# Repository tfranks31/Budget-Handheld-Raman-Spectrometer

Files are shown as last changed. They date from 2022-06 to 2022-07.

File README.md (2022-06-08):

# Budget-Handheld-Raman-Spectrometer
An inexpensive DIY handheld Raman spectrometer! Ever want to make a handheld Raman spectrometer for under $300?
Probably not! However, matter is just about everywhere and makes up most of everything. It would be cool to have a 
device that tells you what something is made out of, and would be even cooler to build it yourself!

This repository serves as the main repository for this project, and contains source code, electrical schematics, CAD 
models, future plans, and documentation for it all.

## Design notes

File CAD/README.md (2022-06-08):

# CAD Models
Here exist all CAD models used for the handheld Raman spectrometer project.

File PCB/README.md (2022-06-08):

# PCB design and electrical schematics
Here exists all PCB designs and electrical schematics for the handheld Raman spectrometer project.

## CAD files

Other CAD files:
CAD/Collimating Ring.f3d
CAD/Longpass Ring.f3d
CAD/Test Stand.f3d

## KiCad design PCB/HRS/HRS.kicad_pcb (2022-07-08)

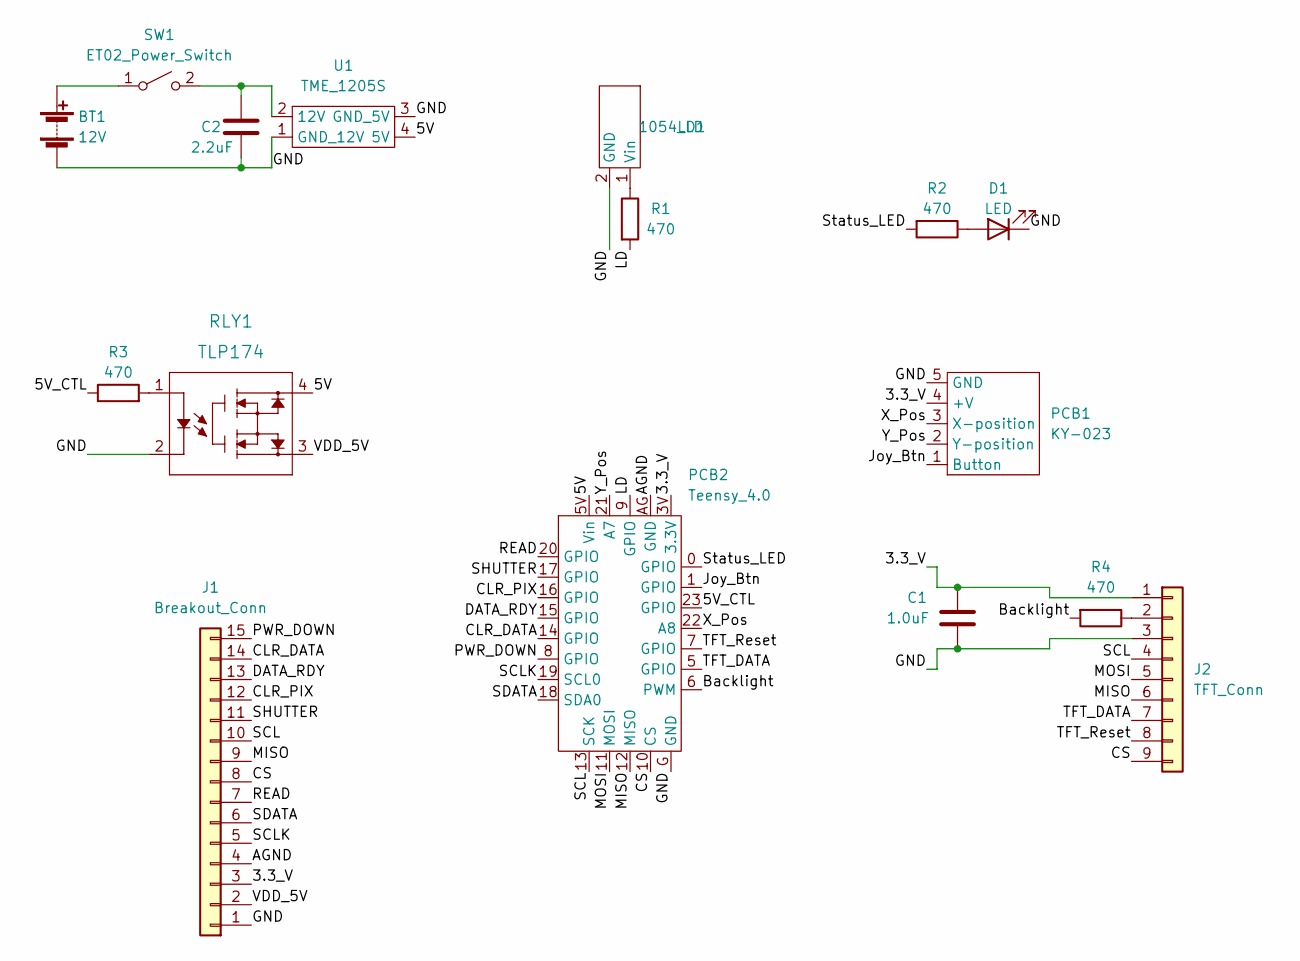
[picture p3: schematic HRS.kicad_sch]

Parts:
BT1: 12V; BAT&LD
C1: 1.0uF; C_0603_1608Metric
C2: 2.2uF; C_0603_1608Metric
D1: LED; LED_D5.0mm
J1: Breakout_Conn; Breakout-Connector-Female
J2: TFT_Conn
LD1: 1054_LD; BAT&LD
PCB1: KY-023; Ky-023
PCB2: Teensy_4.0; Teensy Headers
R1, R2, R3, R4: 470; R_0603_1608Metric
RLY1: TLP174
SW1: ET02_Power_Switch; ET02
U1: TME_1205S; TME 1205S

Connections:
/3.3_V: C1.2, J1.3, J2.1, PCB1.4 (+V), PCB2.3V (3.3V)
/5V: PCB2.5V (Vin), RLY1.4, U1.4 (5V)
/5V_CTL: PCB2.23 (GPIO), R3.1
/AGND: J1.4, PCB2.AG (GND)
/Backlight: PCB2.6 (PWM), R4.2
/CLR_DATA: J1.14, PCB2.14 (GPIO)
/CLR_PIX: J1.12, PCB2.16 (GPIO)
/CS: J1.8, J2.9, PCB2.10 (CS)
/DATA_RDY: J1.13, PCB2.15 (GPIO)
/GND: BT1.2 (-), C1.1, C2.1, D1.1 (K), J1.1, J2.3, LD1.2 (GND), PCB1.5 (GND), PCB2.G (GND), RLY1.2, U1.1 (GND_12V), U1.3 (GND_5V)
/Joy_Btn: PCB1.1 (Button), PCB2.1 (GPIO)
/LD: PCB2.9 (GPIO), R1.2
/MISO: J1.9, J2.6, PCB2.12 (MISO)
/MOSI: J2.5, PCB2.11 (MOSI)
/PWR_DOWN: J1.15, PCB2.8 (GPIO)
/READ: J1.7, PCB2.20 (GPIO)
/SCL: J1.10, J2.4, PCB2.13 (SCK)
/SCLK: J1.5, PCB2.19 (SCL0)
/SDATA: J1.6, PCB2.18 (SDA0)
/SHUTTER: J1.11, PCB2.17 (GPIO)
/Status_LED: PCB2.0 (GPIO), R2.2
/TFT_DATA: J2.7, PCB2.5 (GPIO)
/TFT_Reset: J2.8, PCB2.7 (GPIO)
/VDD_5V: J1.2, RLY1.3
/X_Pos: PCB1.3 (X-position), PCB2.22 (A8)
/Y_Pos: PCB1.2 (Y-position), PCB2.21 (A7)
unnamed: BT1.1 (+), SW1.1 (A)
unnamed: C2.2, SW1.2 (B), U1.2 (12V)
unnamed: D1.2 (A), R2.1
unnamed: J2.2, R4.1
unnamed: LD1.1 (Vin), R1.1
unnamed: R3.2, RLY1.1

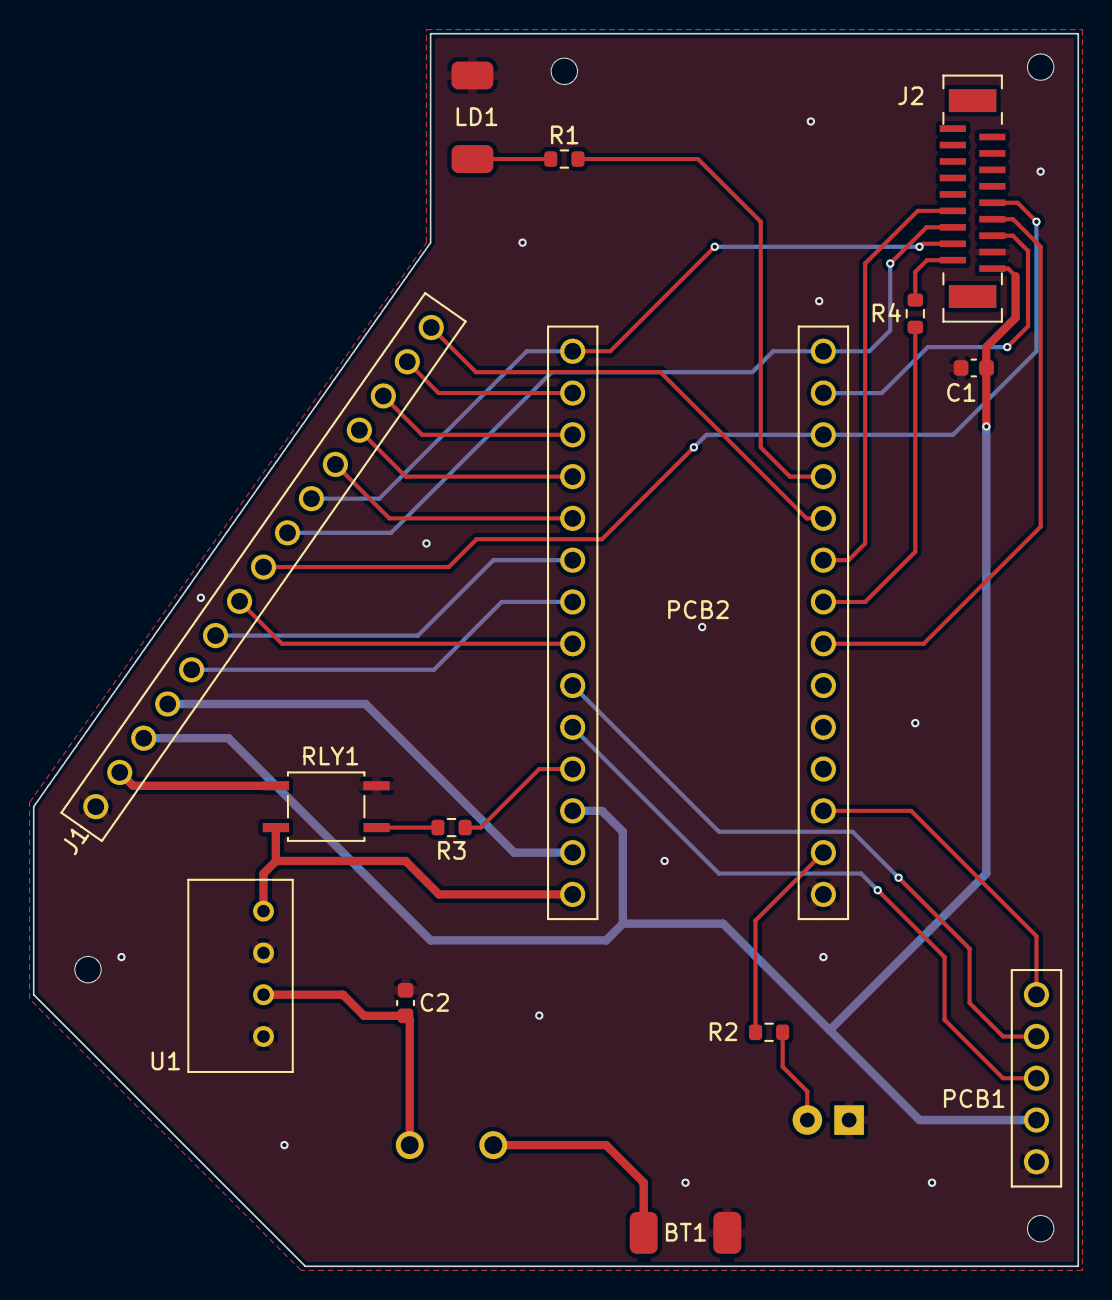
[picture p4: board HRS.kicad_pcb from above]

Board: 2 copper layers, 63.5 x 74.9 mm, 16 parts (0 on the bottom side), 32 nets.

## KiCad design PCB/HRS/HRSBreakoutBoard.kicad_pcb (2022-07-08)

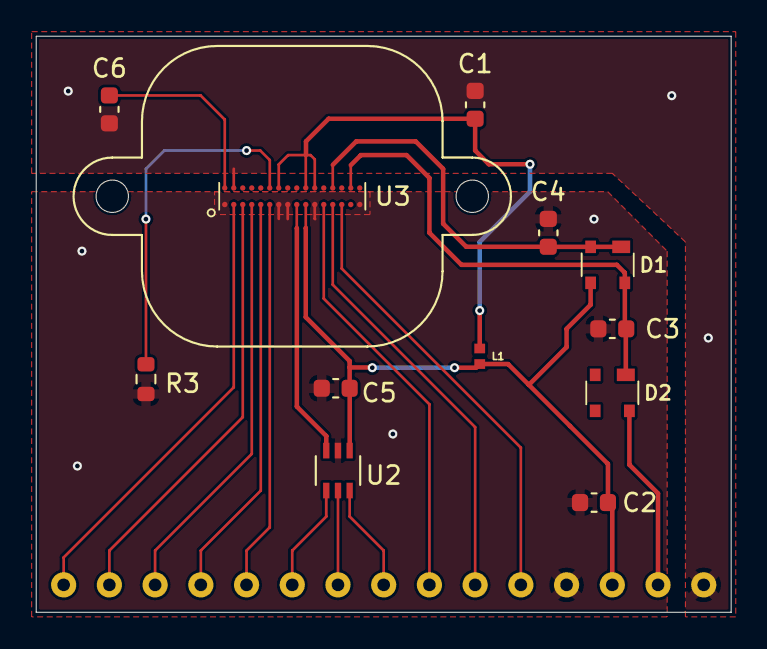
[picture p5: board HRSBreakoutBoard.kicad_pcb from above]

Board: 2 copper layers, 38.6 x 32.0 mm, 13 parts (0 on the bottom side), 21 nets.

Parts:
C1, C2, C5, C6: 1.0uF; C_0603_1608Metric
C3, C4: 2.2uF; C_0603_1608Metric
D1, D2: BAT74,215; SOT143(B)
J1: Conn_01x15; Breakout Board Connector
L1: 600; BEADC1005X55N
R3: 56k; R_0603_1608Metric
U2: AD7476A; AD7476
U3: epc901; EPC901

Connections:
/AGND: C2.2, C3.1, C4.1, C5.1, J1.12, R3.2, U2.2 (GND), U3.1 (AGND), U3.7 (GND_OA), U3.8 (VIDEO_N), U3.11 (VIDEO_CM), U3.16 (AGND)
/CLR_DATA: J1.2, U3.3 (CLR_DATA)
/CLR_PIX: J1.4, U3.5 (CLR_PIX)
/DATA_RDY: J1.3, U3.4 (DATA_RDY)
/DGND: C1.1, C6.1, J1.15, U3.31 (DGND)
/PWR_DOWN: J1.1, U3.2 (PWR_DOWN)
/READ: J1.9, U3.12 (READ)
/SCL: J1.11, U3.14 (SCL)
/SCLK: J1.6, U2.4 (SCLK)
/SDA: J1.10, U3.13 (SDA)
/SDATA: J1.7, U2.5 (SDATA)
/SHUTTER: J1.5, U3.6 (SHUTTER)
/VDD: C1.2, L1.2, U3.22 (BW0), U3.23 (BW1), U3.26 (VDD)
/VDD_3V: C2.1, C5.2, D1.3, J1.13, L1.1, U2.1 (VDD), U3.10 (VDD_OA)
/VDD_5V: D2.4, J1.14
/VDD_5V0: C3.2, D1.4, D2.1, U3.18 (VDD_5V0)
/VDD_7V0: C4.2, D1.1, D1.2, U3.20 (VDD_7V0)
/VIDEO_P: U2.3 (VIN), U3.9 (VIDEO_P)
/~CS: J1.8, U2.6 (~CS)
unnamed: C6.2, U3.32 (VDD_1V8)
unnamed: R3.1, U3.27 (I_BIAS)

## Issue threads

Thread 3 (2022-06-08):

Source Battery and Voltage Conversion Needs

tfranks31, 2022-06-08:
### Proposed work
A battery and some kind of voltage conversion still need to be sourced. Worst case scenario, the instrument will draw 200mAh max. Under normal operation (scanning and viewing display), it will likely draw 100mAh max. The maximum voltage needed for operation is 5V.

Preferably, find a power source that is either rechargeable or can be easily replaced (ex. multiple AAs).
### Task list
- [x] Investigate rechargeable power source options
- [x] Investigate battery packs that allow for common battery replacement
- [x] If needed, investigate methods of controlling the battery output voltage
- [x] Make a decision and order

Closed 2022-06-10.

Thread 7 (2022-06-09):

Design PCBs

tfranks31, 2022-06-09:
### Proposed work
Create the initial PCB designs to be used for this project. Create the schematics for all components and convert them to PCB layouts. Two PCBs need to be made. One main PCB for the majority of the system, and another breakout board for the CCD detector and ADC.
### Task list
- [x] #8
- [x] #16
- [x] Determine layout for breakout board
- [x] Lay traces for breakout board
- [x] #9
- [x] #17
- [x] Determine layout for main PCB
- [x] Lay traces for main PCB

Closed 2022-07-08.

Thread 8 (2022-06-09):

Create Breakout Board Schematics

tfranks31, 2022-06-09:
### Proposed work
Create all of the breakout board schematics. This involves creating schematics for the CCD, ADC, connectors out to the main PCB, and any resistors, capacitors, and/or diodes needed.
### Task list
- [x] Create CCD schematic
- [x] Create ADC schematic
- [x] Create board connector schematic
- [x] Connect schematics as needed

Closed 2022-06-20.

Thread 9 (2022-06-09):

Create Main PCB Schematics

tfranks31, 2022-06-09:
### Proposed work
Create the main PCB schematic. This involves connection points for the laser, Display, joystick, and breakout board. This also involves creating the connection points for the Teensy and room for the battery module and potential voltage regulator module. Add any resistors, capacitors, or diodes as necessary.
### Task list
- [x] Create Laser schematic
- [x] Create Display connector schematic
- [x] Create Joystick connector schematic
- [x] Create breakout board connector schematic
- [x] Create Teensy connector schematic
- [x] Create power schematic
- [x] Create status LED and button schematics
- [x] Connect schematics as needed

Closed 2022-06-26.

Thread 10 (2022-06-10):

Design Optics Casing

tfranks31, 2022-06-10:
### Proposed work
The optics equipment used needs casing to hold the lens and filter.  Design cases for each of them.
### Task list
- [x] Design case for collimating lens
- [x] Design case for filter
- [x] 3d print them

Closed 2022-07-28.

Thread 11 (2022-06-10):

Design Optics Stands

tfranks31, 2022-06-10:
### Proposed work
Most optical components will need a stand of some sort for demonstration purposes. Build little optics stands to hold them.
### Task list
- [x] Design stand for laser
- [x] Design stand for collimating lens
- [x] Design stand for filter
- [x] Design stand for Diffraction grating
- [x] 3d print the stands

Closed 2022-07-28.

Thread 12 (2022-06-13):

Determine Unit Test Framework and Hardware Simulation Support

tfranks31, 2022-06-13:
### Proposed work
Platform.io offers an integrated unit testing framework. Learn more about and figure out what needs to be done to integrate with it. There are also hardware simulators that can be interfaced with the unit testing framework. Research them and set up a hardware simulator for the project's hardware configuration.
### Task list
- [x] Investigate Platform.io unit testing
- [x] Investigate hardware simulators
- [x] Choose and setup a hardware simulator to be used with the project

tfranks31, 2022-12-31:
PlatformIO integrates Unity testing, which will be the test framework used. Full MC/DC coverage will be aimed at when writing tests, but no formal testing tool will be used to measure coverage. Further investigation also prompted the decision to develop our own simulated hardware. A new hardware interface layer will need to be introduced so that tests can use the simulated hardware modules instead of physical hardware modules. Also, we will begin to profile each function/method within the codebase. A mark of how long each function/method takes will be added as a comment to the header. These profiles will be re-run each time a function/method is created or updated, as well as any functions/methods that rely on it. These will be profiled with actual hardware attached to obtain actual performance.

Closed 2022-12-31.

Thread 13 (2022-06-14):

Re-do Breakout Board Symbols and Simplify the Schematic

tfranks31, 2022-06-14:
### Proposed work
The EPC901 symbol was created quickly and does not complement the breakout board schematic. Change the symbol to complement it and help de-clutter the schematic.
### Task list
- [x] Redesign EPC901 symbol
- [x] Redesign ADC symbol
- [x] Retrace for simplicity

Closed 2022-06-20.

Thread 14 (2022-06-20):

Test All Received Components

tfranks31, 2022-06-20:
### Proposed work
All electrical components have arrived and need to be tested for proper behavior. Take each component, assemble it if necessary, and verify that the hardware works as expected.

### Task list
- [x] Assemble Teensy Pins
- [x] Test Teensy
- [x] Test Laser Diode
- [x] Test Diffraction Grating
- [x] Test Display Cable and connector
- [x] Test TFT Display
- [x] Test Battery Holder with Snap
- [x] Test DC converter
- [x] Test Joystick
- [x] Test LED
- [x] Test button
- [x] Test LLC

Closed 2022-06-25.

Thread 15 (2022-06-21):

Source 5V Power Control Component

tfranks31, 2022-06-21:
### Proposed work
The CCD detector requires a 5V source to operate in low power mode. The problem is that the 5V source needs to wait at least 100ms after receiving 3.3V. The microcontroller will control this. Find a component that will satisfy these requirements. Look into MOSFETs, Relays, and whatever other switching components you can find.
### Task list
- [ ] Research electronic switch options
- [ ] Source the component

Closed 2022-06-23.

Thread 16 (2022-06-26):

Create Footprints for Breakout Board

tfranks31, 2022-06-26:
### Proposed work
Footprints need to be created for all of the PCB components. Create them!
### Task list
- [x] Create footprint for the header pins connector
- [x] Create footprint for the ADC
- [x] Create footprint for the CCD
- [x] Create footprints for all minor parts

Closed 2022-07-02.

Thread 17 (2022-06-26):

Create Footprints for main PCB

tfranks31, 2022-06-26:
### Proposed work
Footprints need to be created for all of the PCB components. Create them!
### Task list
- [x] Create footprint for battery connection
- [x] Create footprint for power switch
- [x] Create footprint for DC converter
- [x] Create footprint for LLC
- [x] Create footprint for LD connection
- [x] Create footprint for status LED
- [x] Create footprint for joystick module
- [x] Create footprint for breakout board connection
- [x] Create footprint for TFT connection
- [x] Create footprint for Teensy connection
- [x] Create footprint for all minor parts

Closed 2022-07-02.

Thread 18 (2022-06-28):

Make electrical schematics "electrical correctness" friendly

tfranks31, 2022-06-28:
### Proposed work
KiKad has the ability to assert electrical correctness for schematics, but doing so requires further work updating the schematics. Update the schematics to support this ability.
### Task list
- [ ] Convert breakout board schematics
- [ ] Convert main PCB schematics

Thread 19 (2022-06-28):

Create Circuit Simulations to Verify Correctness and Introduce Noise

tfranks31, 2022-06-28:
### Proposed work
LTspice is a circuit simulator. Create the circuits used in this project in LTspice to verify correctness and to see how the circuits handle the noise that was characterized.
### Task list
- [ ] Create breakout board simulation
- [ ] Create main PCB simulation

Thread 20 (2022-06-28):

Characterize Noise

tfranks31, 2022-06-28:
### Proposed work
With all that is going on with the system, the power supply and analog signals may be very noisy. Characterize it and document it for future improvements.
### Task list
- [ ] Characterize all power supply noise
- [ ] Characterize all analog noise

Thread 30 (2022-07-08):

Add Back Pink Borders to PCB Footprints

tfranks31, 2022-07-08:
### Proposed work
Didn't realize at the time what the Pink boundaries were for, but they were removed when assembling the PCB footprints. They are used to indicate their workable area and used to detect when components are getting too close. Add them back to all the footprints.
### Task list
- [x] Add boundaries to breakout footprints
- [x] Add boundaries to main footprints

Closed 2022-08-25.

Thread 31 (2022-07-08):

Optimize PCBs

tfranks31, 2022-07-08:
### Proposed work
The first rev of the PCBs is complete! However, there are many things that can likely be changed and improved upon. Look at the tasks below for how to improve upon them.
### Task list
- [x] Move parts closer
- [x] Make edges tighter
- [x] Reroute for best paths
- [x] Better separate digital and analog planes of the PCB
- [x] Minimize as much as reasonably possible
- [x] Remove unnecessary laser resistor
- [x] Remove unnecessary backlight resistor
- [x] Enlarge header pin size on breakout board
- [x] #43
- [x] Enlarge lens holes
- [x] Enlarge and plate mounting holes

Closed 2022-08-24.

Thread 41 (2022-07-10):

Add De-Bounce Circuit to Joystick Button

tfranks31, 2022-07-10:
### Proposed work
Currently, we debounce the Joystick button in software, using a timer interrupt. Its a good fix, but there is still some room for improvement. Moving the debounce to the hardware side would improve resource usage and stop edge cases.
### Task list
- [ ] Move debounce to PCB

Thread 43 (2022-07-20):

Fix the CS Pins

tfranks31, 2022-07-20:
### Proposed work
The CS pins got messed up. I thought the TFT CS was logic level high, it turns out it isn't, which means it needs to be separated from the ADC CS.
### Task list
- [x] Route a new trace from an open pin to act as a new CS

Closed 2022-08-23.

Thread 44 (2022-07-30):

Solder PCBs

tfranks31, 2022-07-30:
### Proposed work
Solder the PCBs!
### Task list
- [x] Solder the breakout board components
- [x] Solder the main board components
- [x] Set up the test setup

Closed 2022-07-31.

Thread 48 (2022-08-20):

Source and Implement EEPROM

tfranks31, 2022-08-20:
### Proposed work
We need an EEPROM on the device to store captured spectra. Look for one, primarily one that can communicate over I2C, and integrate it into the PCB.
### Task list
- [x] Source EEPROM
- [x] Create EEPROM symbol
- [x] Add EEPROM to schematic
- [x] Create EEPROM footprint
- [x] Add EEPROM to PCB

Closed 2022-08-23.

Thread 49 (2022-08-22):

Source and Implement Terminal Blocks

tfranks31, 2022-08-22:
### Proposed work
After some concerns with wire tension, ripping PCB pads off, and potentially faulty components, it was decided that some sort of connector should be added. However, due to my lack of understanding of crimping, choosing, and assembling connectors, it was decided that terminal blocks would be the easiest way to reduce wire tension and allow for replaceable components. Find PCB terminal blocks for the laser module and the battery connector.
### Task list
- [x] Source terminal blocks
- [x] Create terminal block symbol
- [x] Add terminal blocks to schematic
- [x] Create terminal block footprint
- [x] Add terminal block to PCB

Closed 2022-08-23.

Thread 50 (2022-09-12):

Model and Print First Version of the Encasing

tfranks31, 2022-09-12:
### Proposed work
Time to model the case! Model the first version.
### Task list
- [x] Model Handle
- [x] Model PCB Housing
- [x] Compute angle for diffraction grating and lenses
- [x] Model optics housing
- [x] Make assemblable
- [x] Model different heads
- [x] Modify until properly fitted

Closed 2022-10-12.

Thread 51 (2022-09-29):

Make models for all non-case hardware

tfranks31, 2022-09-29:
### Proposed work
While designing the case, I discovered how much of a pain it is to measure physical models and use those measurements to determine placement. It would be much easier if I had models of each external hardware piece for easier visualization and placement checks.
### Task list
- [ ] Create populated PCB model
- [ ] Create TFT model
- [ ] Create Diffraction Grating model
- [ ] Create ribbon cable model
- [ ] Create Battery holder, snap, and battery models
- [ ] Create Laser model

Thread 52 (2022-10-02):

Add checks to all interval timers to see if the resource is available

tfranks31, 2022-10-02:
### Proposed work
Turns out that if all interval timers are in use, the call simply returns false, and does not block. While the teensy has 4 timers, all of them can potentially be used at the same time (frame timer, led timer, joystick button timer, and shutter timer). External libraries may also use the timers, so we need to check if they are available, and wait until they are.
### Task list
- [x] Go through all interval timer uses, add checks for their return value for all .begin() calls, and delay until the timer resource is available again

Closed 2022-11-16.

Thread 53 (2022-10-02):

Add pullup resistors to I2C line

tfranks31, 2022-10-02:
### Proposed work
Turns out that the pullup resistors on the Teensy 4.0 aren't that great for I2C communication and they can only support 100kHz rates. It would be nice to have 400kHz speeds, especially for data initialization and upload. Teeny's website says that adding 1k-4.7k resistors should work.
### Task list
- [ ] Add pullup resistor to SDA and SCL lines

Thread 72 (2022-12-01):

Create Scan Processing Class

tfranks31, 2022-12-01:
### Proposed work
We need to do much processing with the scanned in data from the CCD. This involves scaling the ADC readings, Denoising the signal with baseline correction, and providing means of comparison between scans. All of these should be placed under a scan processing class.
### Task list
- [ ] Create ADC scaler
- [ ] Create Denoise and Baseline correction algorithm using wavelet transforms
- [ ] Create scan comparison algorithm

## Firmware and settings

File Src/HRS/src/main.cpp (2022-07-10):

#include <Arduino.h>
#include <SPI.h>
#include <Adafruit_I2CDevice.h>
#include <module_controllers/LEDController.hpp>
#include <module_controllers/LaserController.hpp>
#include <module_controllers/JoystickController.hpp>
JoystickController* jcntr = new JoystickController(22, 21, 1);
void setup()
{
    LEDController* controller = new LEDController(0);
    controller->bringOnline();
    controller->runScanningMode();

    LaserController* lcntr = new LaserController(9);
    lcntr->bringOnline();
    lcntr->setIntensity(255);
    lcntr->turnOn();

    
    jcntr->bringOnline();
}

void loop()
{
    Serial.print("Hor:  ");
    Serial.println(jcntr->getHorizontalMovement());
    Serial.print("Vert: ");
    Serial.println(jcntr->getVerticalMovement());
    Serial.println(jcntr->getButtonPressed());
    Serial.println();
    jcntr->clearButtonPressed();
    delay(500);
}

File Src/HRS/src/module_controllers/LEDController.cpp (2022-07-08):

#include <module_controllers/LEDController.hpp>

// NOTE: Static variables and functions had to be used in order to interact with
// them in the timer ISR. 
/**
 * The system's status LED.
 */
LED* LEDController::statusLED;

/**
 * The interval timer used to implement LED modes.
 */
IntervalTimer* LEDController::timer;

/**
 * If the LED is fading, whether or not to fade upwards
 */
bool LEDController::fadeUp;

/**
 * Track the number of heart beats
 */
uint8_t LEDController::numBeats;

LEDController::LEDController(uint8_t pinNum)
{
    statusLED = new LED(pinNum);
    timer = new IntervalTimer();
}

LEDController::~LEDController()
{
    bringOffline();
    delete timer;
    delete statusLED;
}

void LEDController::bringOnline()
{
    statusLED->init();
    runIdleMode();
}

void LEDController::bringOffline()
{
    timer->end();
    statusLED->turnOff();
}

void LEDController::runIdleMode()
{
    // Set up and run the LED in heartbeat mode
    timer->begin(heartbeatLED, HEARTBEAT_LONG_RATE);
    statusLED->setBrightness(MAX_BRIGHTNESS);
    statusLED->turnOff();
    numBeats = 0;
}

void LEDController::runScanningMode()
{
    // Set up and run the LED in fade mode
    timer->begin(fadeLED, FADE_RATE);
    statusLED->setBrightness(0);
    statusLED->turnOn();
    fadeUp = true;
}

void LEDController::runErrorMode()
{
    // Error mode is just toggling the LED
    timer->begin(toggleLED, TOGGLE_RATE);
    statusLED->setBrightness(MAX_BRIGHTNESS);
}

void LEDController::heartbeatLED()
{
    // We use the number of "beats" to track how many times the LED state has
    // changed. The LED will be toggled for ever timer iteration, with the
    // difference being how long until the next LED toggle.
    if ((numBeats + 1) / 2 == MAX_NUM_BEATS)
    {
        // We finished our heartbeat(s), reset and wait a for the next beats
        timer->begin(heartbeatLED, HEARTBEAT_LONG_RATE);
        numBeats = 0;
    }
    else
    {
        // We just started the next series of beats, set the timer short and
        // start beating
        if (numBeats == 0)
        {
            timer->begin(heartbeatLED, HEARTBEAT_SHORT_RATE);
        }
        numBeats++;
    }
    toggleLED();
}

void LEDController::fadeLED()
{
    // Increase brightness if we are fading up
    if (fadeUp)
    {
        uint8_t newBrightness = statusLED->getBrightness() + 1;
        statusLED->setBrightness(newBrightness);

        // We reached the maximum brightness, start fading down
        if (newBrightness == MAX_BRIGHTNESS)
        {
            fadeUp = false;
        }
    }
    // Decrease brightness if we are fading down
    else
    {
        uint8_t newBrightness = statusLED->getBrightness() - 1;
        statusLED->setBrightness(newBrightness);
        
        // We reached the lowest brightness, start fading up
        if (newBrightness == 0)
        {
            fadeUp = true;
        }
    }
}

void LEDController::toggleLED()
{
    statusLED->getIsOn() ? statusLED->turnOff() : statusLED->turnOn();
}

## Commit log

2022-06-13 Added more datasheets and created Platform.io framework
2022-06-26 Added schematics and symbols for pcb
    [HRS.kicad_pcb, HRS.kicad_sch, HRSBreakoutBoard.kicad_sch]
2022-07-02 Completed footprints and schematics
    [HRS.kicad_sch, HRSBreakoutBoard.kicad_sch]
2022-07-03 Added resistor for TFT backlight
    [HRS.kicad_sch]
2022-07-03 Created led module header
2022-07-03 Created and implemented led module
2022-07-03 Renamed LED files and created LEDController files
2022-07-03 Created LEDController header file
2022-07-04 Started LED modes and created mode enum and timer
2022-07-04 Created all led module functionality
2022-07-04 Finished LED module
2022-07-04 Make led fade rate faster
2022-07-08 Made PCBs
    [HRS.kicad_pcb, HRS.kicad_sch, HRSBreakoutBoard.kicad_pcb]
2022-07-08 Added laser module class
2022-07-08 Created laser module cpp
2022-07-09 Created LaserController header
2022-07-09 Created LaserController implementation
2022-07-09 Added bring online and offline functionality to LaserController
2022-07-09 Added interrupt for button press and moved clearButtonPress
2022-07-10 Created JoystickController and made minor fixes
    [Joystick.cpp, main.cpp]
2022-07-10 Created button press timer to ignore bounces
2022-07-10 Fixed comments and created constant
    [Joystick.cpp]
2022-07-17 Added relay header
2022-07-17 Created relay module implementation
2022-07-17 Created relay controller header
2022-07-18 Implemented relay controller
2022-07-18 Added CAD models for testing
    [Collimating Ring.f3d, Longpass Ring.f3d, Test Stand.f3d]
